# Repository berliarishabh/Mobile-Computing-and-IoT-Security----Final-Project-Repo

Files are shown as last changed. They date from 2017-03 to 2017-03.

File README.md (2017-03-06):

# Mobile-Computing-and-IoT-Security----Final-Project-Repo

#### Motivation:

With the advent of mass-deployed broadband Internet connections and the development of Wireless technologies (BLE, Zigbee etc.), smart connected devices in the home are a very real and practical possibility. 

A Smart Home is one that is designed to deliver or distribute a number of services within and outside the home through a range of networked devices. [Juniper Research]

#### Objective:

To develop a complete Internet of Thing system for a Smart Home such as Samsung SmartThings, Notion etc. This would require us to build individual BLE based Sensor Tags. Every Tag would have a specific sensor to sense parameters such as Temperature, Humidity, Ambient Light, Proximity, Pressure, Touch etc. 
These Tags will be built on the BLE Nano (based on the Nordic nRF51822 SoC). Each individual tag will have the sensor circuit interfaced with the BLE Nano and would run on a single coin-cell battery (CR-2032). We would use the Leopard Gecko EFM32 Board as one of the Tags as well to use the LESENSE sensor. 

The Sensor Tags would connect and transmit data to a small Microcomputer (Raspberry Pi 3) based hub. Since, the Raspberry Pi has Wi-Fi connectivity it enables us to take our data to the cloud, where the data processing would take place. 

We plan to use one of the following platforms to collect, visualize & analyze data and trigger responses accordingly:
•	Sci-kit Learn
•	ThingSpeak
•	Phant
This would allow us to host a web server on Rasp Pi for the User Interface where the User can monitor all the sensor data on Graphs and Issue Override Commands such as GetTemp, GetPressure etc.
If we are able to accomplish this well within our time bounds, we would try to implement an App to give notifications on the Phone.

Also, since we have the sensor data and trigger points we could use to actuate physical things inside your home e.g. Using the Ambient light and Temperature sensor data, a servo motor could be used to actuate your Window Blinds depending on the Light and temperature settings etc. 

There would be 2 set of Commands, Trigger Commands and Override Commands. 
Trigger Commands are sent through the ThingSpeak or Sci-Kit platform depending on the set points. If the sensor data goes above or below a notification would be given. These commands are even used to Actuate something if required.

Override Commands are sent by the user through the UI, these commands are to get the most recent Sensor Data and post it on the Screen.

#### Block Diagram of a System
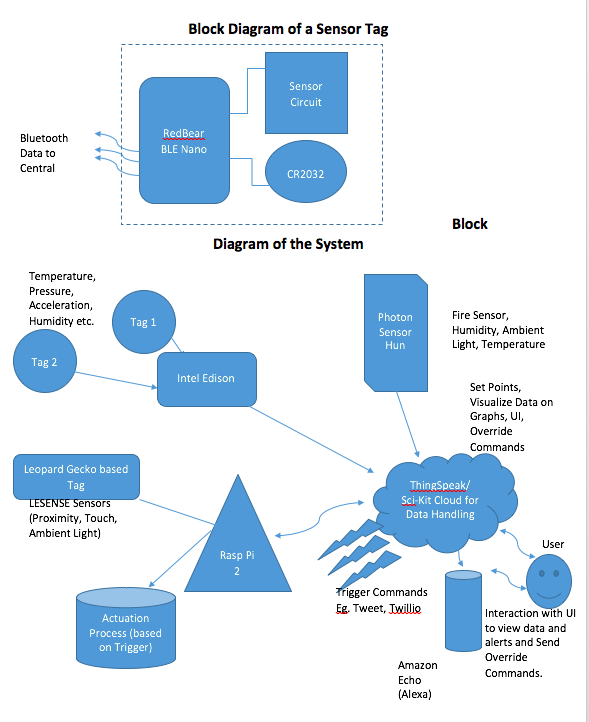
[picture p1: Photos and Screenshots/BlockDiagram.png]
block-diag


#### Block Diagram of the System
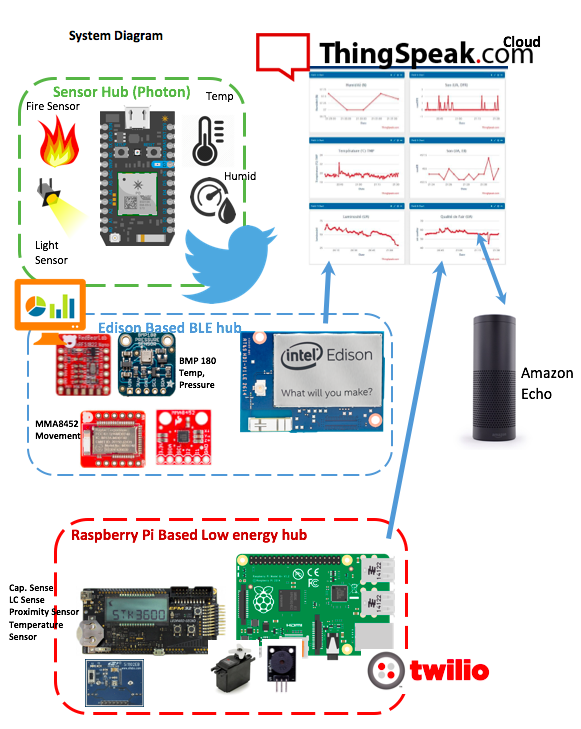
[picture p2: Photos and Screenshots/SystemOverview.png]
System-d


#### Test Methodology: 

1.	Testing functionality of individual Sensor Tags
  a.	Validate sensor data 
  b.	Testing if sensor tag posts data according to Set Points
  c.	Testing if sensor tag sends data when requested with a command.
2.	Testing the Server
  a.	Test individual sensor connections to the server
  b.	Test the Data Logging and setup Visualization through Graphs.
  c.	Testing the Trigger commands and Override Commands
3.	Integration and Testing
  Integration of the system and testing individual points

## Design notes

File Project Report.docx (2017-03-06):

Project Report

Handout

ECEN 5023:

Mobile Computing and IoT Security

Rishabh Berlia

Omkar Reddy Seelam

Proposed Objective¹:

c

1 As Submitted in Project Proposal

What was Implemented?

We were able to finish most of the Objectives we set.

There are 3 different modules in our Project. The first one Sensor Cubes.

We built 2 Sensor Cubes (instead of calling them tags). They are based on BLE Nano with an ARM M0 Processor. One Sensor Cube is for Temperature and Pressure (It has a BMP180 sensor on it). The other one is for Movement Detection (It has a MMA8452Q accelerometer.) Both the sensors communicate using I2C protocol.

They communicate with the Intel Edison Over Bluetooth protocol using the Bluez Python Library. The received data is then transmitted to the ThingSpeak channel.

The second one is a Sensor Hub based on Particle Photon Board. It is a Wi-Fi connectable board. It has a Thermistor, a Photocell Based Light Sensor, Fire Detection Sensor, Humidity Sensor. This peripheral boxes in one Housing and connects to the ThingSpeak cloud similarly via HTTP request. The Sensors in this hub are both Analog and Digital ones.

The third module or peripheral is the Leopard Gecko board, used in the class. This uses the Adafruit Bluefruit LE UART Friend connected to a Raspberry Pi via a Bluetooth 4.0. We built upon the Adafruit Python Library to send data from the Leopard Gecko to the Pi. We get the data as a 9bit string and parse the data accordingly. The data is then updated on ThingSpeak at the given interval.

We also implemented the Amazon Echo to act as the center of the Smart Home system. It helps you to read the sensor data and also send commands to the system.

System Diagram

Cloud

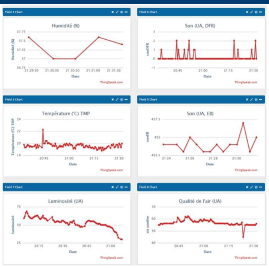
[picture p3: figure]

Sensor Hub (Photon)

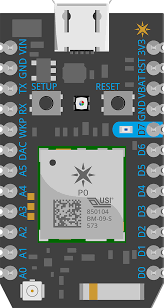
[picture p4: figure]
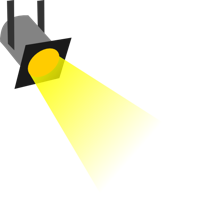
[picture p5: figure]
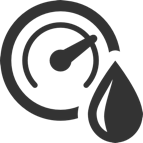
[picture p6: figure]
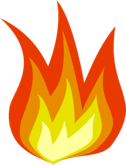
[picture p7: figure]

Fire Sensor

Temp Sensore

Humid Se

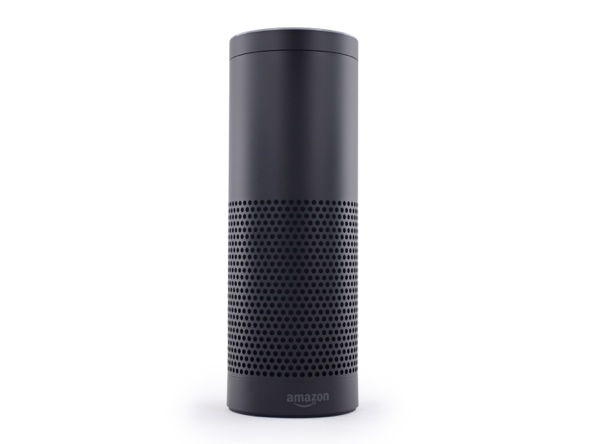
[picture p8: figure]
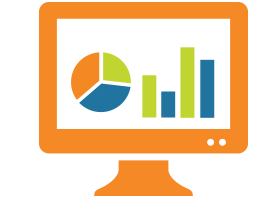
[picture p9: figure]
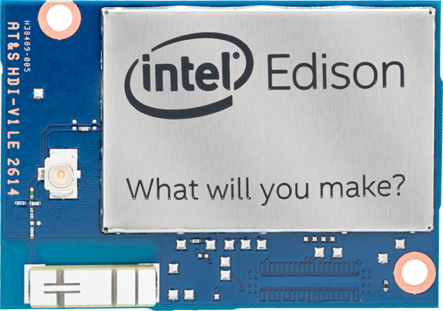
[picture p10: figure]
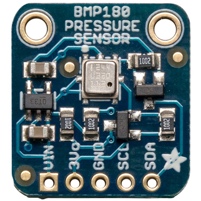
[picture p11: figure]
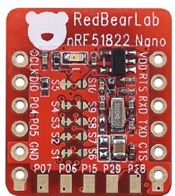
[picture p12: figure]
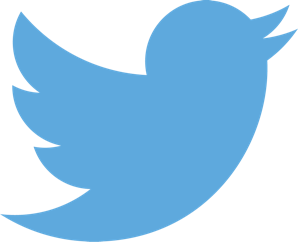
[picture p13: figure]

Light Sensor

MMA8452

Movement

BMP 180

Temp, Pressure

Amazon Echo

Edison Based BLE hub

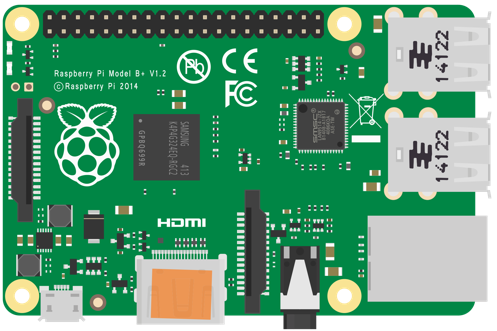
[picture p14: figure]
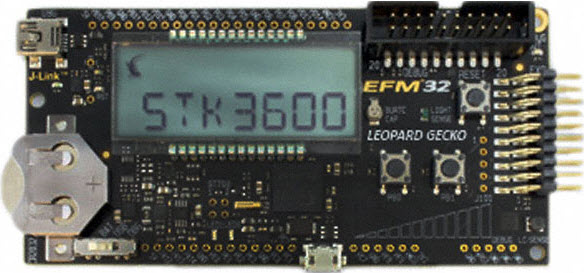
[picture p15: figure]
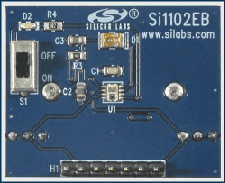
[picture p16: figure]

Raspberry Pi Based Low energy hub

Cap. Sense

LC Sense

Proximity Sensor

Temperature Sensor

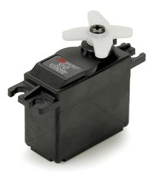
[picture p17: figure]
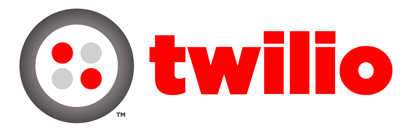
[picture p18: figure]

Block Diagram of a Sensor Tag

Sensor Circuit

RedBear

BLE Nano

Bluetooth Data to Central

CR2032

Block Diagram of the System

Photon Sensor Hun

Temperature, Pressure, Acceleration, Humidity etc.

Tag 1

Fire Sensor, Humidity, Ambient Light, Temperature

Tag 2

Intel Edison

Set Points, Visualize Data on Graphs, UI, Override Commands

Leopard Gecko based Tag

ThingSpeak/ Sci-Kit Cloud for Data Handling

Rasp Pi 2

LESENSE Sensors (Proximity, Touch, Ambient Light)

User

Trigger Commands

Eg. Tweet, Twillio

Actuation Process (based on Trigger)

Interaction with UI to view data and alerts and Send Override Commands.

Amazon Echo (Alexa)

Issues and What could not be completed.

We were aiming to also integrate the TI sensor tag in the system but we had some problems in reading data from it. Also we broke the side switch which is used to switch the system ON.

Also we are having problems with sending commands using Alexa. This is due to the University’s Private Network. We need a public IP to get the data from Alexa to actuate something.

We implemented the EEPROM Emulation but there are inconsistencies with our code.

We believe we could have made the system more consistent and given a better demo without making you and Shiva wait.

Summary

This was a very challenging project. We had a lot in mind and were able to implement most of it. We learnt a lot of new things.

We leant in depth about BLE services and learned to make a custom service. We still have to learn to write code to read from the custom library. This is the reason we have used existed profiles (Heart Rate) to receive data/send data.

We learnt different platforms to create a multiprotocol Wireless Sensor Network. Interfaced different IoT APIs with our project.

We learnt the Alexa API which is really fun to use. We created some models using sketch-up and learnt some 3D prototyping.

We learnt that anything that can go wrong will go wrong! You just have to be agile. Try to fix things with a new approach. We kept pretty much to the timeline apart from a few deviations.

We learnt Python in more depth. Also got to try a couple of new sensors.

Key Dates:

Duration (Week) | Task
~~03-13 to 03-19 (Week 1)~~ | ~~Acquiring Parts and Research~~
~~03-20 to 03-26 (Week 2)~~ | ~~Getting Sensor Tags ready (almost done)~~
~~03-27 to 04-02 (Week 3)~~ | ~~Finishing up with Sensor Tags~~
~~04-03 to 04-09 (Week 4)~~ | ~~Setting up the Sensor Network on Raspberry PI~~ ~~Complete Sensor Tags~~
~~04-10 to 04-16 (Week 5)~~ | ~~Setting up the Web Server using selected Platform~~ ~~EEPROM Emulation~~
04-17 to 04-23 (Week 6) | ~~Complete an Actuation System like the Automatic Window Blinds.~~ Integration with Amazon Echo
04-23 to 04-25 (Week 7) | Testing and Finishing up
04-26 (Week 7) | Project Demo

We kept to the schedule more or less which has happened the first time with us. It was due to the timely updates and status reports that were required which pushed us to complete our work on time.

Photos

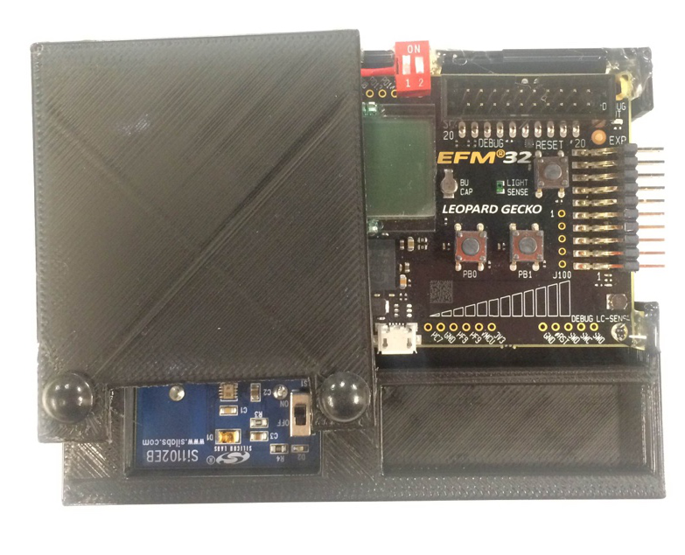
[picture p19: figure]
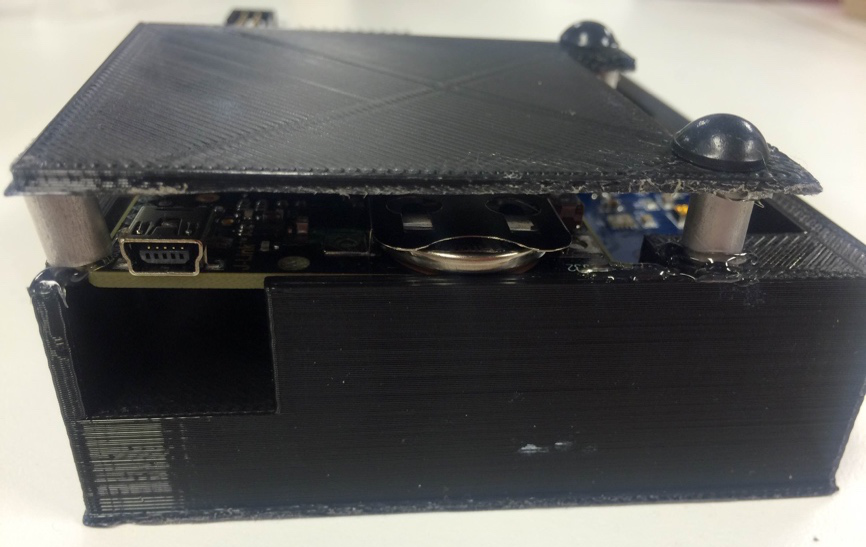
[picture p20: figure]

Figure 1 Leopard Gecko with housing (Top View)

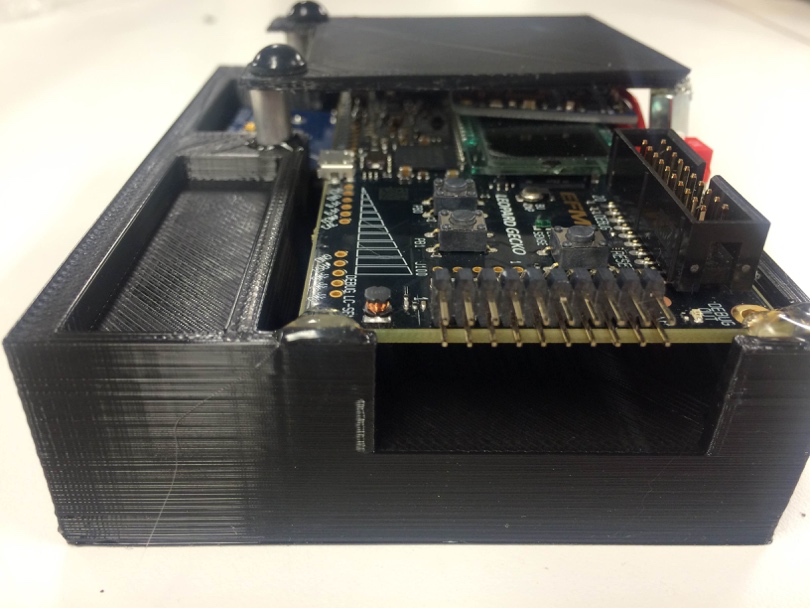
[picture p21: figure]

Figure 2 Leopard Gecko (Side View 1)

Figure 3 Leopard Gecko (Side View 2)

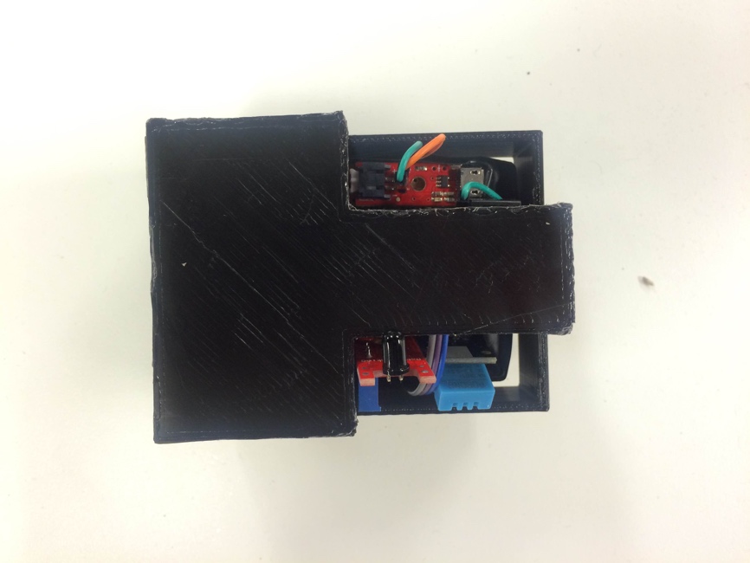
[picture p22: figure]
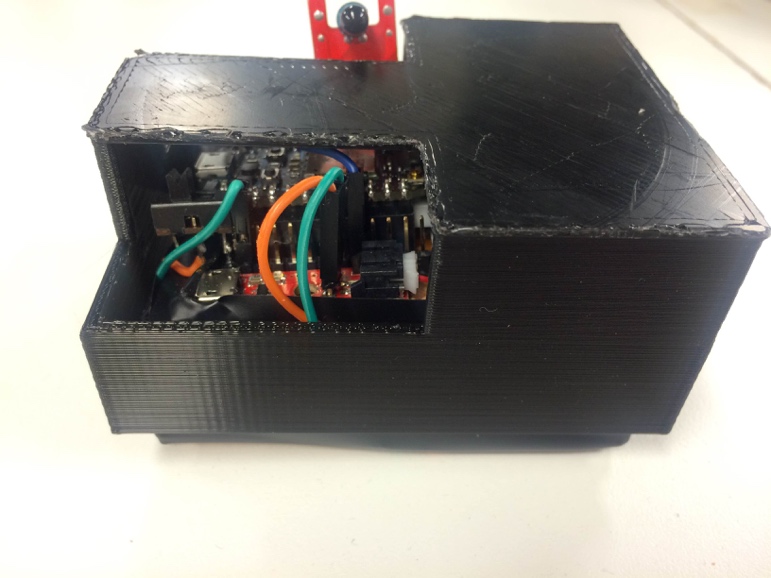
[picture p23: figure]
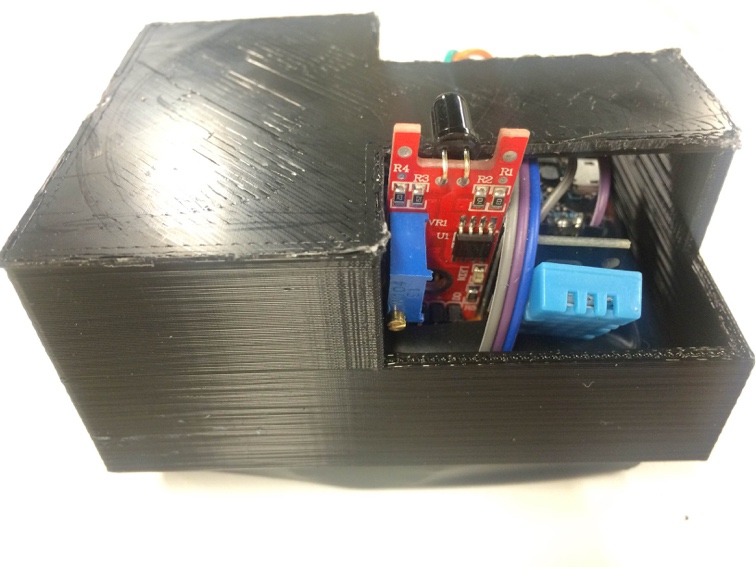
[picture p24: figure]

Figure 4 Photon Sensor Hub with Housing (Side View 1)

Figure 5 Photon Sensor Hub with Housing (Side View 2)

Figure 6 Photon Sensor Hub with Housing (Top View)

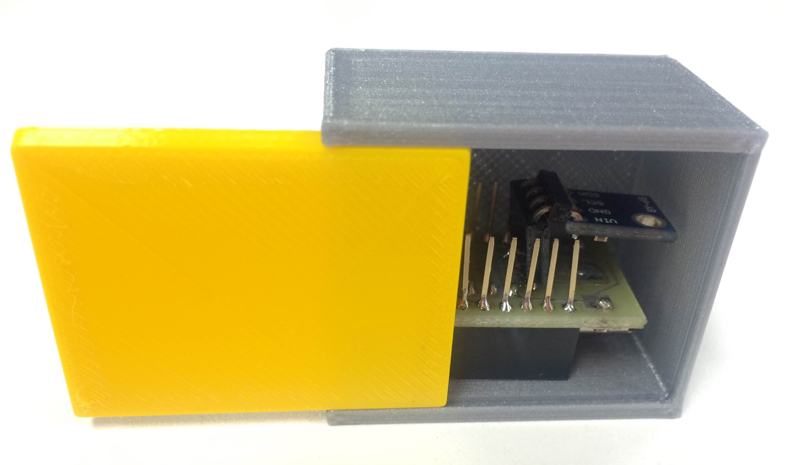
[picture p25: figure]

Figure 7 Accelerometer Cube (with Red Bear Nano)

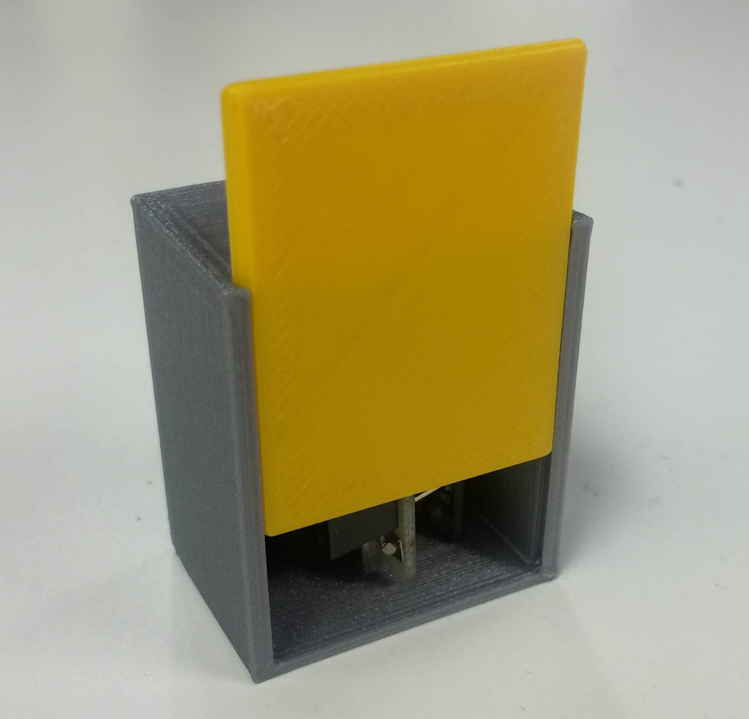
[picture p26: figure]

Figure 8 Temperature and Pressure Cube (with Red Bear Nano)

Acknowledgements

We would like to conclude by thanking a few people without whose help this project would have not been possible.

Firstly, we would like to Thank you Prof. Graham for scoping the project so well and giving us ample time for the project. We really liked the way the project was structured with the regular updates, it pushed us to complete it on time.

We would also Thank you for the forum and helping everyone through that medium, though we were not able to use that help much I believe it was really helpful for other students.

We would also extend our thanks to our TA, Shivashankar Gunashekhar for his help and suggestions during the project and otherwise. He has been a really hard-working TA and helped a lot of students like us during the entire semster. We would also Thank our friend Akshay Singh for helping us during the HackCU.

Lastly we would like to thank our friend from Aerospace Engineering for helping us in making the 3D parts using solid-works, without her help it wouldn’t have been easier to make the parts this quickly.

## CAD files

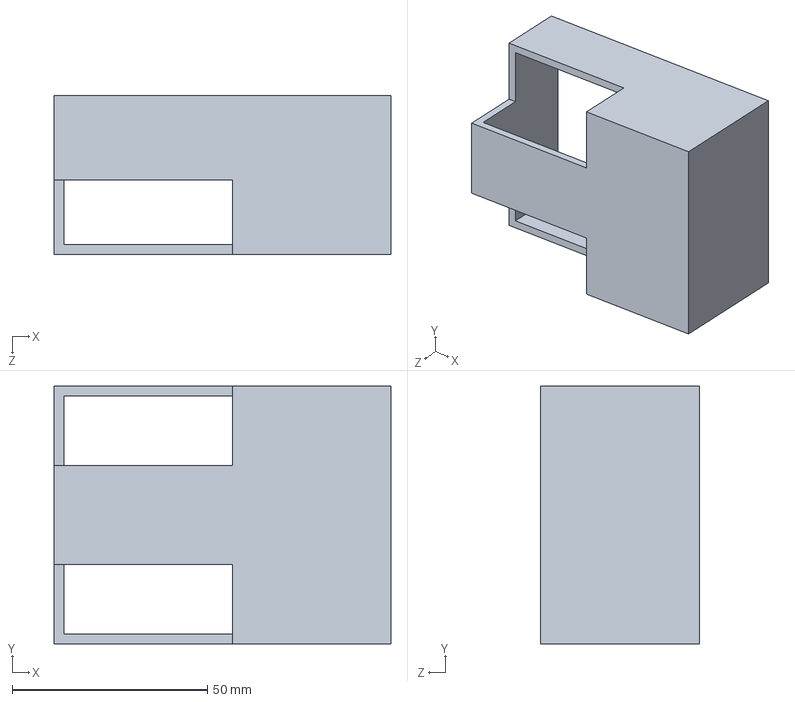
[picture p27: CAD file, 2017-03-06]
Schematics and Solidworks Parts/3D Printed Parts/PhotonBox.SLDPRT
86.4 x 66.0 x 40.6 mm

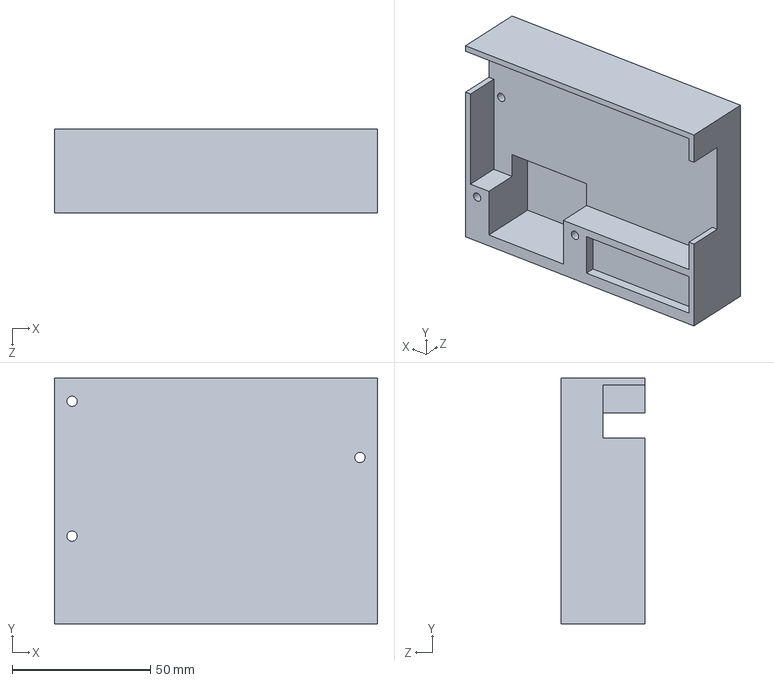
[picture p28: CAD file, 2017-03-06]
Schematics and Solidworks Parts/3D Printed Parts/Base_Gecko.SLDPRT
116.8 x 88.9 x 30.5 mm

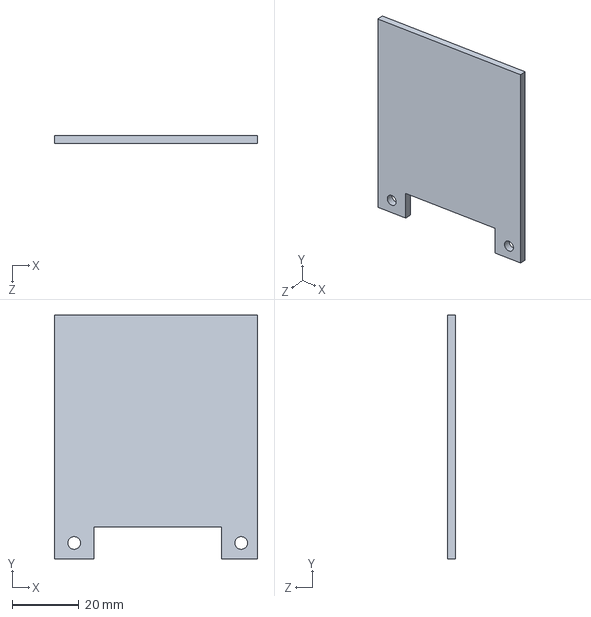
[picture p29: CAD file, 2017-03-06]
Schematics and Solidworks Parts/3D Printed Parts/TOP_Plate_Gecko.SLDPRT
61.0 x 73.1 x 2.54 mm

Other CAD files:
Schematics and Solidworks Parts/3D Printed Parts/Base_Gecko.STL
Schematics and Solidworks Parts/3D Printed Parts/PhotonBox.STL
Schematics and Solidworks Parts/3D Printed Parts/TOP_Plate_Gecko.STL

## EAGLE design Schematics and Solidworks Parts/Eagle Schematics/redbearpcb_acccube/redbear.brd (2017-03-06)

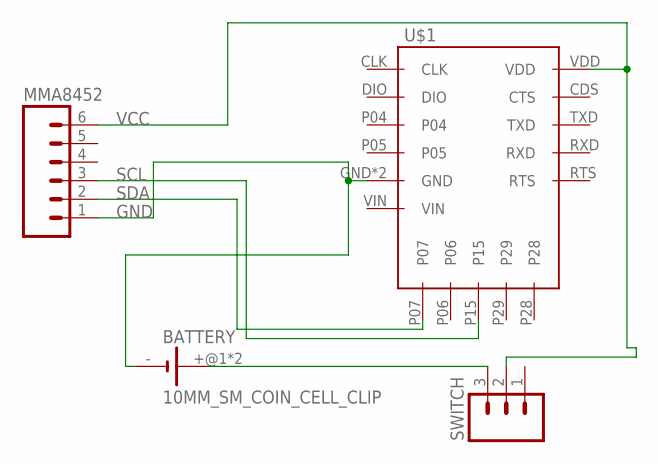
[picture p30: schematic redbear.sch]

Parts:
BATTERY: 10MM_SM_COIN_CELL_CLIP
MMA8452: M06NO_SILK_FEMALE_PTH; 1X06_NO_SILK
SWITCH: M03PTH; 1X03
U$1: REDBEAR_NANOBREAKOUT1; BREAKOUT

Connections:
GND: BATTERY.-, MMA8452.1, U$1.GND, U$1.GND1 (GND)
unnamed: BATTERY.+@1 (+), BATTERY.+@2 (+), SWITCH.3
SCL: MMA8452.3, U$1.P15
SDA: MMA8452.2, U$1.P07
VCC: MMA8452.6, SWITCH.2, U$1.VDD

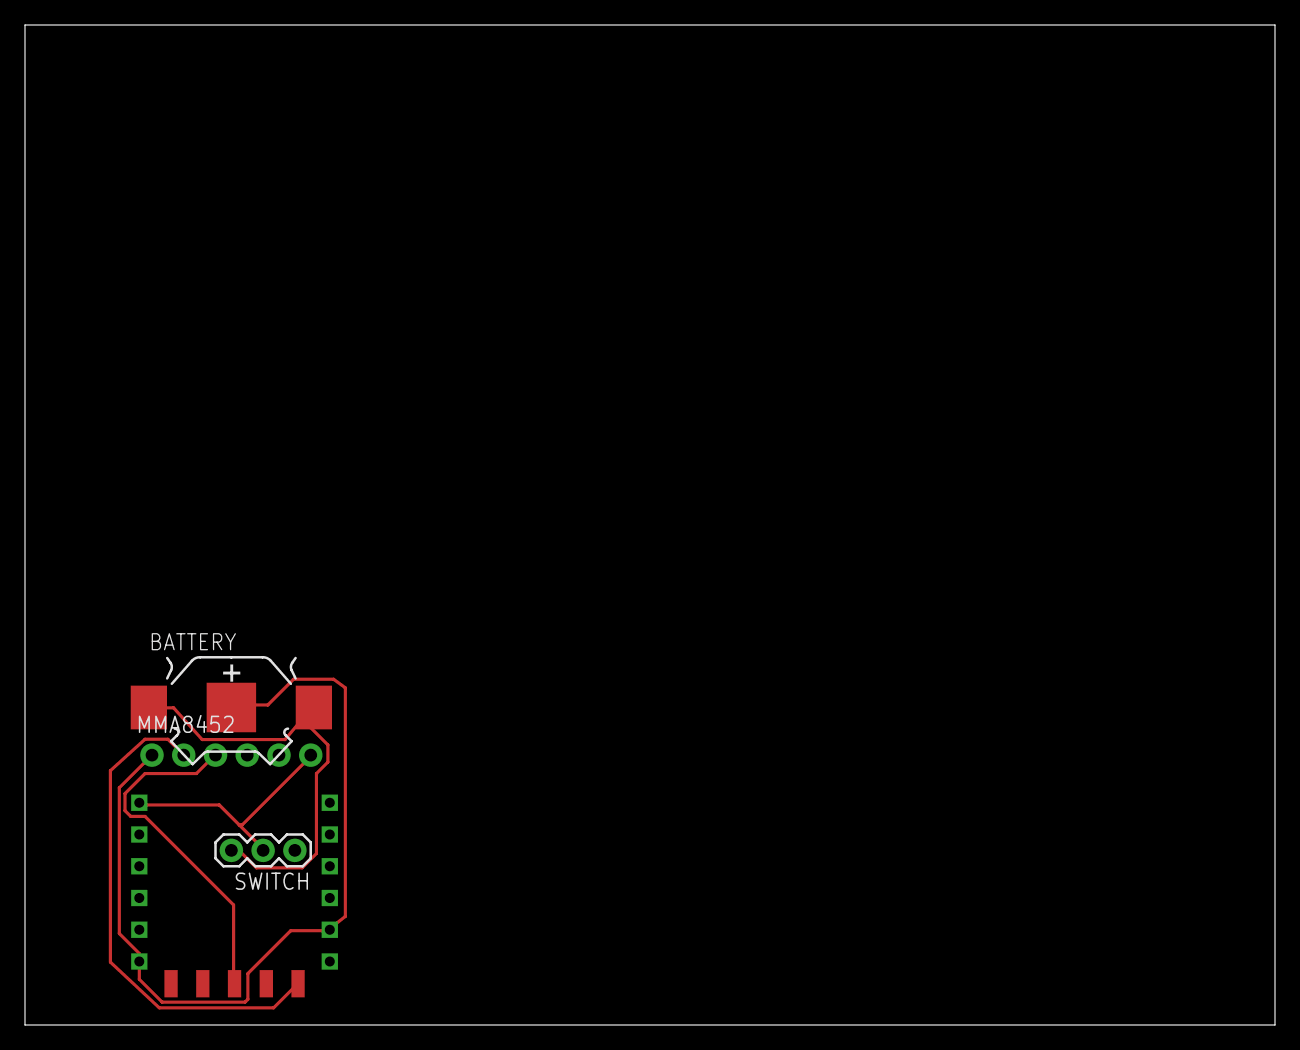
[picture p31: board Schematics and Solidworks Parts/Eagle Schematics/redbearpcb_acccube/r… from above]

Board: 2 copper layers, 100.0 x 80.0 mm, 4 parts (0 on the bottom side), 5 nets.

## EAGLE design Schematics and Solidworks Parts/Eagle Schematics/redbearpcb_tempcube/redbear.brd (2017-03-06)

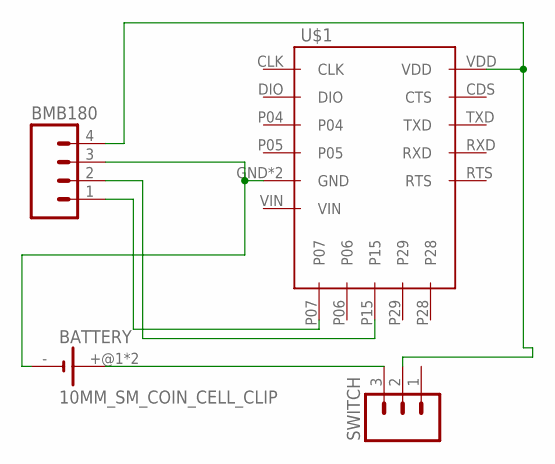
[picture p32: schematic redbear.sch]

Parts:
BATTERY: 10MM_SM_COIN_CELL_CLIP
BMB180: M04NO_SILK_ALL_ROUND; 1X04_NO_SILK_ALL_ROUND
SWITCH: M03PTH; 1X03
U$1: REDBEAR_NANOBREAKOUT1; BREAKOUT

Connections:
GND: BATTERY.-, BMB180.3, U$1.GND, U$1.GND1 (GND)
unnamed: BATTERY.+@1 (+), BATTERY.+@2 (+), SWITCH.3
SCL: BMB180.2, U$1.P15
SDA: BMB180.1, U$1.P07
VCC: BMB180.4, SWITCH.2, U$1.VDD

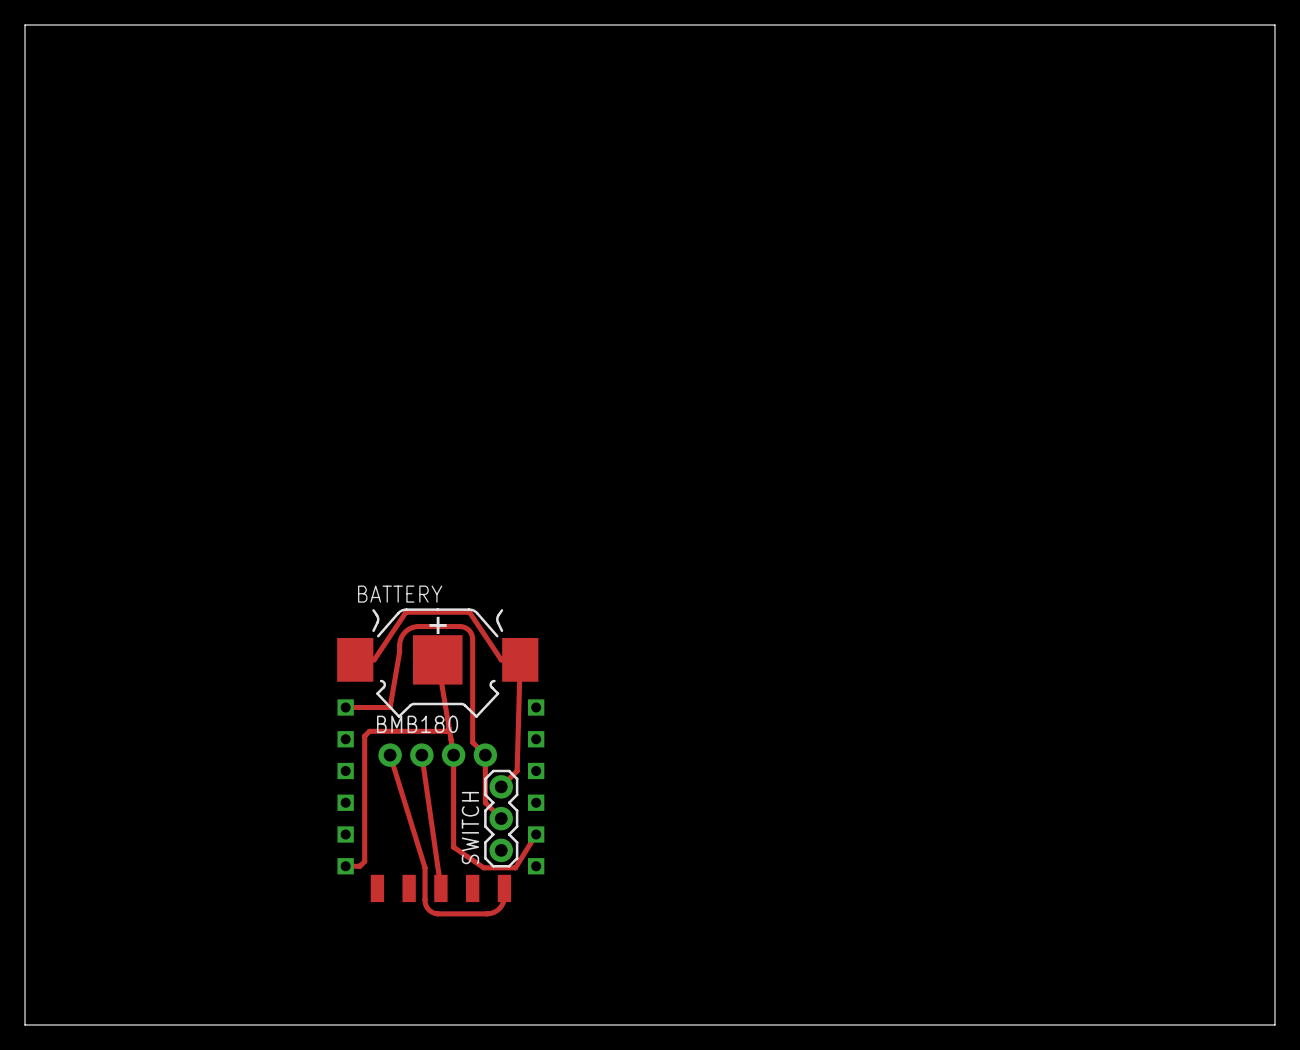
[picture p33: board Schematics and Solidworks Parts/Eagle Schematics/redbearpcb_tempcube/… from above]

Board: 2 copper layers, 100.0 x 80.0 mm, 4 parts (0 on the bottom side), 5 nets.

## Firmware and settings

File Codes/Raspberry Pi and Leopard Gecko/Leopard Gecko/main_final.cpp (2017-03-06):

/************************************************************************************************************
* Description :	Part of the Final Project for the Course Mobile Computing and IoT Security (ECEN5023)		*
* Author	  :	Omkar Reddy Seelam and Rishabh Berlia                                                       *
* Email		  : omkar.reddy15@gmail.com, omkar.seelam@colorado.edu, rishabh.berlia@colorado.edu				*
* Date		  : 4/28/2016																					*
************************************************************************************************************/

/* Features:
 * Sometimes the alerts are too frequent and redundant so, the alerts can be snoozed for certain time  : snoozeAlerts!
 * Fixed issues like multiple LESENSE sensors DMA_Tx overwrites (Used an if loop to check what sensors have been triggered)
 * Negative temperatures issue has been fixed
 *
 * Different modes:
 * ***** Verbose mode : Where it sends lengthy messages such as "The temp is ....."
 * ***** switchToRPi : Where it waits for the command from the RPi whenever requested and responds accordingly
 * ***** !switchToRPi (default mode) : In which the LG sends a custom 9 Byte data packet every 4 seconds. The data packet has following info:
 * 										Y/N : {IntrusionState, DoorState, LightState, SecurityState, Temperature : +/- XX.X}
 * 										The main idea was that the sensors modify the data packet whenever a change in state is observed using interrupts
 * 										and the current data packet at each 4 seconds interval is sent through bluetooth.
 * 						You can switch between switchToRPi modes using the PusbButton0
 * Monitored using:
 * ***** The program has been structured in a way that it provides flexibility to use the LG with a RPi or
 * 		 any BLE application on a SmartPhone or computer.
 * 		 This can be done using the pushbutton0.
 *		 Care has been taken such that the sensor data stream sent makes sense not only for a RPi but also on the applications.
 *		 For this reason the custom packet of 9 bytes mentioned above has been chosen.
 * */

/* Project Requirements:
 * EEPROM Emulation has been implemented to restore the SecurityState during a reset, but it was not consistent. Did not get enough time to fix the issue.
 * */

/* LC SENSE + LIGHT SENSE + TEMPERATURE SENSE
 * 1. LESENSE AND TEMP SENSE LEUART DMA_TX dont overwrite. If there is a LEUART DMA_Tx in progress, it simply skips any new LEUART DMA_Tx requests
 * 2. In this version IF LIGHT SENSE DMA_Tx requests (if LC AND LIGHT are both on), because LC SENSE is being serviced first in the LESENSE IRQ.
 * 		A way has to be implemented to not skip any of the particular LESENSE DMA_Tx reqyests by using multiple combinations of
 * 3. LCSENSE Snooze has been made global to all the LESENSE sensors; All alerts will be snoozed
 * */

/* LC Sensor + ADC Temperature Sensor (from Assignment 5)
	1. multiple DMA writes dont interrupt the previous write;
	2. Simply skips the new write if an existing DMA LEUART Tx is happening; Used DMA_IDLE flag
*/

/* LC SENSOR FINAL:
 * 1. Turns on LED0 when the window is open (when there is no metal)
 * 	  There is LETIMER0 interrupting every 4 seconds; If the LED0 is on, then it is turned off; If there is no metal
 * 	  	detected in the next scan cycle; The Led0 is immediately turned on again.
 * 	  	So, a On/Off of LED0 can be observed when there is no metal nearby.
 * 2. Notifications sent through BLE when there is no metal nearby i.e, when window is open. Notified every scan cycle
 * 3. Notifications can be snoozed for about LCSENSE_SNOOZECOUNT times the LETIMER0 interrupts => (SnoozeCount * LETIMER0 interrupts)
 * 		After the snooze time, the notifications resume if the window is still open;
 * 		Meanwhile the LED0 performs the same behaviour of On/Off during the entire snooze cycle or untill a metal comes nearby i.e, until the window is closed
 * . The Threshold for LC Sensor is hardcoded; Should implement a way in which the input is taken from the user
 * */

// Include Libraries
#include "mbed.h"       // mbed libraries; includes sleep()
#include "em_device.h"
#include "em_chip.h"    // for chip related libraries
#include "sleepmodes.h" // to use blockSleepMode() and unblockSleepMode()
#include "em_letimer.h"	// for LETIMER functions; LETIMER_CompareSet, etc
#include "em_gpio.h"	// For GPIO setup
#include "em_adc.h"		// For ADC
#include "em_dma.h"		// For the DMA
#include "em_leuart.h"	// For the LEUART
#include "string.h"		// For string manipulation functions; string copy, string concatenation
#include "em_lesense.h"	// For LESENSE setup
#include "em_acmp.h"	// ACMP used for sensor measurements (LESENSE)
#include "em_dac.h"		// DAC used for excitation and reference (LESENSE)
#include "em_int.h"		// For Enabling/Disable Interrupts Globally
#include "em_i2c.h"
#include "i2c_api.h"
#include "eeprom_emulation.h"

/* MACROS DECLARATION */
#define BLE_COMPLETELY_OFF					true

// BLE Connection to either SmartHome System (final project) or on the APP (for debug)
#define BLE_VERBOSE							false
#define LIGHTSENSE_TIMER_RESET				true
#define LCSENSE_TIMER_RESET					true
#define LIGHTSENSE_TIMEOUT					false
#define LCSENSE_TIMEOUT						false
#define SWITCHTORPI_BUTTON_PORT				gpioPortB
#define SWITCHTORPI_BUTTON_PIN				9U
#define SWITCHTORPI_BUTTON					SW0					// or PB9
uint32_t smartHome_temperature = 0;								// Temperature part of the packet
uint32_t smartHome_security = 0;								// Sends the security fields
char smartHomeMessage[] = "NNNN+00.0\r\n";						// Y/N : {Proximity, LC, LIGHT, SECURITY, +/- XX.X}
char command_smartHomeMessage[] = "leopardPacket!";
bool switchToRPi = false;										// Doesnt send message every 4 seconds. Sends data only when requested. Can be done by using a timer on RPi
char switchingToRPi[] = "Switching to RPi\r\n";
char switchingBackFromRPi[] = "Switching back from RPi\r\n";
bool LIGHTSENSE_TIMER = LIGHTSENSE_TIMER_RESET;					// defaulted to true
bool LCSENSE_TIMER = LCSENSE_TIMER_RESET;							// defaulted to true
InterruptIn	switchTORPi_button(SW0);

// Common Variables
#define DEBUG_MODE 					0						// Make this value to 0; To enable Serial print and BCP trace (code-correlation)
#define LOWPOWER_USING_SLEEPONEXIT 	0						// Using SLEEPONEXIT; Even Lower Energy program can be achieved
#define INV_LEUART_DATABITS			0						// Invert LEUART Data bits; While not transmitting

// LETIMER Variables
#define ULFRCO_Freq 				1000					// Frequency of ULFRCO is 1KHz
#define SAMPLEPERIOD 				4						// Total Required period in Seconds

// DMA Setup Variables
#define DMA_CHANNEL_ADC 			2						// DMA channel select - ADC0
#define DMA_CHANNEL_LEUART_RX 		0						// DMA channel select - LEUART RX
#define DMA_CHANNEL_LEUART_TX 		1						// DMA channel select - LEUART TX
#define DMA_ADC_PRIORITY 			false					// DMA Channel Priority for ADC
#define DMA_LEUART_TX_PRIORITY 		false					// DMA Channel Priority for	LEUART TX
#define DMA_LEUART_RX_PRIORITY 		false					// DMA Channel Priority for LEUART RX
#define DMA_ADC_ARBITRATE 			dmaArbitrate1			// ADC Arbitrate rate
#define DMA_LEUARTRX_ARBITRATE 		dmaArbitrate1			// LEUART RX Arbitrate rate
#define DMA_LEUARTTX_ARBITRATE 		dmaArbitrate1			// LEUART TX Arbitrate rate
#define LEUART0_BUFF_MAX 			1023					// Buffer size for LEUART0
#define DMA_LEUARTRX_TRANSFERS 		LEUART0_BUFF_MAX 		// DMA Transfers to be done on LEUART0->RXDATA

// ADC Setup Variables
#define ADC_SAMPLESREQUIRED 		200						// The required number of samples
#define ADC_REFERENCE 				adcRef1V25				// Single Conversion Reference for Temperature sensor
#define ADC_INPUTCHANNEL 			adcSingleInpTemp		// Selecting the input channel; Temperature sensor
#define ADC_RESOLUTION 				adcRes12Bit				// Selecting the resolution
#define ADC_ACQTIMECYCLES 			adcAcqTime2				// Calculated Acquisition time
#define ADC_CLOCKFREQ 				857000					// Required ADC Clock Frequency

// LEUART Setup Variables
#define LEUART0_LOOP_BACK			false
#define LEUART0_BAUDRATE 			9600					// LEUART0 BaudRate
#define LEUART0_DATABITS 			leuartDatabits8			// Number of data bits for LEUART0
#define LEUART0_PARITY 				leuartNoParity			// Parity bit enable/disable
#define LEUART0_STOPBITS 			leuartStopbits1			// Number of Stop bits
#define LEUART0_SIGFRAME			'!'						// The SIG Frame for LEUART0

// Temperature Settings

#define TEMP_UPPERLIMIT_DEFAULT 			30						// Temperature Sensor Upper Limit = 30degreesC [LED1]
#define TEMP_LOWERLIMIT_DEFAULT 			15						// Temperature Sensor Upper Limit = 15degreesC [LED0]

#define TEMPERATURE_SIZE					8						// Size of the Temperature reading appended to the transmitted message
#define CHECK_NEGATIVE_TEMPERATURES			false					// Flag to check if negative temp are being printer; subtracts 25 degrees

// GPIO variables
#define LED_PORT 					gpioPortE				// LED pin port
#define LED0_PIN 					2U						// LED0 Pin
#define LED1_PIN 					3U						// LED1 Pin
#define LED_PORT_DRIVEMODE 			gpioDriveModeLowest		// Drive strength for LED0
#define LED_PORT_CONFIG 			gpioModePushPullDrive	// Drive strength for LED1
#define BLUEFRUIT_CTS_PORT			gpioPortD				// Bluefruit CTS Pin connected to PortD of Leopard Gecko
#define BLUEFRUIT_CTS_PIN			15U						// Bluefruit CTS is connected to PortD Pin 15
#define BLE_SWITCH					false
#define BLE_SWITCH_PORT				gpioPortD
#define BLE_SWITCH_PIN				10U
#define PROXIMITY_SENSOR_PORT		gpioPortA
#define PROXIMITY_PIN_VDD			PA14
#define PROXIMITY_PIN_SIG			PA12

// Bluefruit AT Command Variables
#define BLE_CONFIGURATION			false								// Perform BLE Configuration
#define FACTORYRESET				"AT+FACTORYRESET\n"					// Perform Factory Reset before configuring the BLE
#define SWITCHMODE					"+++\n"
#define TX_POWERLEVEL				"AT+BLEPOWERLEVEL=0\n"				// BLE Radio TX power level (dBm); -40,-20,-16,-12,-8,-4,0,4
#define GAP_INTERVAL				"AT+GAPINTERVALS=50,4000,250,50\n"	// (Min ConnInt,Max ConnInt, AdvInt, AdvTimeout)
#define CONNECTION_STATUS			"AT+GAPGETCONN\n"					// Get the connection status
#define HW_MODE_LED					"AT+HWMODELED=disable\n"			// Manipulate HW Mode led; disable(0), mode(1), hwuart(2), bleuart(3), spi(4), manual(5,on/off/toggle)
#define ECHO						"ATE=0\n"							// Enable/Disable Echo
#define SYS_RESET					"ATZ\n"								// System Reset
#define BLE_TIMEOUT					5									// Number of Retries for each command

// LESENSE
#define LESENSE_ACMP_CHANNEL		acmpChannel6	// Doesnt Matter; Any channel can be given because it is controlled by the LESENSE
#define ALERTS_SNOOZECOUNT				10			// LCSENSE Alerts Snooze time is around SnoozeCount*LETIMER_SAMPLEPERIOD
#define LESENSE_CHANNELMASK_6			0x40		// Channal mask for Channel 6 (0x1UL << 6)
#define LESENSE_CHANNELMASK_7			0x80		// Channel mask for Channel 7 (0x1UL << 7)
#define LESENSE_CHANNELMASK_8			0x100		// Channel mask for Channel 8 (0x1UL << 8)
#define LESENSE_CHANNELMASK_11			0x800		// Channel mask for Channel 11(0x1UL << 11)

// LC Sensor Macros
#define LCSENSE_PORT		   		gpioPortC		// LCSENSE Excitation and Measurement Port
#define LCSENSE_PIN			   		7U				// LCSENSE Excitation Measurement Pin
#define LCSENSE_DAC_DATA	   		800				// DAC input for LC Sensor
#define LCSENSE_DAC_CHANNEL	   		1				// DAC Channel for LC Sensor
#define LCSENSE_ACMP_CHANNEL		acmpChannel7	// ACMP Channel for LC Sensor
#define LCSENSE_LESENSE_CHANNEL		7				// LESENSE channel 7 for LC Sensor
#define LCSENSE_LIGHTSENSE_CHANNEL	6				// LESENSE channel 6 for Light Sensor
#define LCSENSE_SCAN_FREQ_Calb		20				// LC Sense Scan Frequency in Hz for Calibration
#define LCSENSE_SCAN_FREQ			1				// LC Sense Scan Frequency in Hz after Calibration
#define ACMP_NEG_REF           		acmpChannelVDD	// Use VDD as ACMP Negative reference
#define ACMP_VDD_SCALE         		0x0D            // Reference for the LC sensor to be close to the DAC voltage This was calibrated using a scope and probing both the LC sensor and the ACMP output
												// From the Software Example
// Calibration Settings
#define LESENSE_MAX_CHANNELS 			16				// LESENSE Channels
#define BUFFER_INDEX_LAST  				15				// Last Buffer Index
#define LCSENSE_MANUAL_THRESHOLD		0x0B			// LCSENSE threshold
#define LCSENSE_THRESHOLD_HYSTERESIS	0x03			// Hysteresis for LC Sense threshold

// LIGHTSENSE Macros
#define LIGHTSENSE_EXCITE_PORT   	gpioPortD
#define LIGHTSENSE_EXCITE_PIN    	6U
#define LIGHTSENSE_SENSOR_PORT   	gpioPortC
#define LIGHTSENSE_SENSOR_PIN    	6U
#define LIGHTSENSE_ACMP_THRESHOLD 	33				// Lesser value means more light needed to turn the LED ON; LED ON => LIGHTS ON
#define LIGHTSENSE_LESENSE_CHANNEL		6

// Capsense
#define CAPSENSE_LESENSE_CHANNEL	8
#define CAPSENSE_PORT				gpioPortC
#define CAPSENSE_PIN				8U

// Proximity Sensor Macros
#define PROXIMITY_PORT				gpioPortA
#define PROXIMITY_PIN				14U
InterruptIn proximitySensorSIG(PROXIMITY_PIN_SIG);

// EEPROM Macros
#define EEPROM_EMULATION			true

/** Default configuration for alternate excitation channel. */
#define LESENSE_LIGHTSENSE_ALTEX_CH_CONF                                       \
{                                                                              \
  true,                   /* Alternate excitation enabled.*/                  \
  lesenseAltExPinIdleDis, /* Alternate excitation pin is low in idle. */ \
  true                    /* Excite only for corresponding channel. */        \
}

/** Default configuration for alternate excitation channel. */
#define LESENSE_LIGHTSENSE_ALTEX_DIS_CH_CONF                                   \
{                                                                              \
  false,                   /* Alternate excitation enabled.*/                  \
  lesenseAltExPinIdleDis,  /* Alternate excitation pin is disabled in idle. */ \
  false                    /* Excite only for corresponding channel. */        \
}

/** Default configuration for all alternate excitation channels. */
#define LESENSE_LIGHTSENSE_ALTEX_CONF                                          \
{                                                                              \
  lesenseAltExMapALTEX,                                                         \
  {                                                                            \
    LESENSE_LIGHTSENSE_ALTEX_CH_CONF,     /* Alternate excitation channel 0. */\
    LESENSE_LIGHTSENSE_ALTEX_DIS_CH_CONF, /* Alternate excitation channel 1. */\
    LESENSE_LIGHTSENSE_ALTEX_DIS_CH_CONF, /* Alternate excitation channel 2. */\
    LESENSE_LIGHTSENSE_ALTEX_DIS_CH_CONF, /* Alternate excitation channel 3. */\
    LESENSE_LIGHTSENSE_ALTEX_DIS_CH_CONF, /* Alternate excitation channel 4. */\
    LESENSE_LIGHTSENSE_ALTEX_DIS_CH_CONF, /* Alternate excitation channel 5. */\
    LESENSE_LIGHTSENSE_ALTEX_DIS_CH_CONF, /* Alternate excitation channel 6. */\
    LESENSE_LIGHTSENSE_ALTEX_DIS_CH_CONF  /* Alternate excitation channel 7. */\
  }                                                                            \
}

/* GLOBAL VARIABLES */
// Common Variables
bool DMA_ADC_transferComplete 	= true;				// Flag to check DMA transfer status of ADC samples
bool DMA_IDLE					= true;
// Enable the Security; Turn the LC Sensor, Light Sensor, Proximity Sensor and Gesture Sensor On
bool SECURITY_ON = false;
DMA_CB_TypeDef cb[DMA_CHAN_COUNT];					// Type Definition for the DMA Call back functions
volatile uint16_t ADC_Buffer[ADC_SAMPLESREQUIRED];	// RAM Buffer for ADC DMA transfer
char Rx_Buffer[LEUART0_BUFF_MAX];		// Receive Buffer for LEUART DMA transfers
float temperature = 0;								// Variable for temperature
uint16_t TEMP_LOWERLIMIT = 0x24;
uint16_t TEMP_UPPERLIMIT = 0x25;
//#if DEBUG_MODE
Serial pc(USBTX, USBRX);    						// To enable pc.printf() statements; un-comment this and use pc.printf("Text\n\r") for printing text on the terminal
//#endif

// LETIMER Variables
uint16_t LETIMER_TOP;								// LETIMER Reset value-COMP0

// LESENSE Global Variables
// LC SENSE
bool CHECK_LCSENSOR_COUNT 		= false;		// To check the count when a metal object is placed/removed
bool MANUAL_THRESHOLD 			= true;
bool NOTIFY_ALERTS 				= true;

// Temperature Sensor Alerts
uint32_t leuartif;													// variable for saving LEUART interrupt flags
char below[] 			= "Temperature BELOW set min : ";			// Lower limit transfer string
char below_negative[] 	= "Temperature BELOW set min: -";			// Lower limit transfer string
char above[] 			= "Temperature ABOVE set max : ";			// Upper limit transfer string
char return_temp[] 		= "\r\nTemperature is : ";					// Return Temperature request string
char return_temp_neg[] 	= "\r\nTemperature is: -";					// Return Temperature request string
char cmdError[] 		= "\r\nERROR: Invalid command\r\n";			// Error message string
char command_RetTemp[] 	= "RetTemp!";								// The command for requesting temperature

// Alerts
char command_alertsSnooze[] 	  = "snoozeAlerts!";							// Command to snooze alerts
char alertsSnoozed[]			  = "\r\nSnoozed alerts for 40s\r\n";				// Response that the alerts have been snoozed
char windowOpenLightOn[]		  = "Window Open, Light On\r\n";				// Alerts
char windowOpenLightOnIntrusion[] = "Window Open, Light On and Intrusion\r\n";
char windowOpenIntrusion[]		  = "Window Open, Intrusion\r\n";
char lightOnIntrusion[] 		  = "Light On, Intrusion\r\n";


// LC Sensor Alerts
char windowOpen[] 		= "Window is open\r\n";					// Alerts
char windowClose[] 		= "Window is closed\r\n";
uint8_t snoozeTime 		= ALERTS_SNOOZECOUNT;					// The default snooze count. It is 10 LETIMER0 interrupt cycles

// Light Sensor Alerts
char lightOn[]			= "Light is On\r\n";					// Alerts

// Cap Sensor Alerts
char command_securityOn[]	= "securityOn!";					// Command to turn on security
char command_securityOff[]	= "securityOff!";
char securityOn[]			= "\r\nSecurity turned On\r\n";
char securityOff[]			= "\r\nSecurity turned Off\r\n";

// Proximity
bool INTRUSION_DETECTED = false;
char intrusion[] = "Intrusion Detected\r\n";

// BLE Configuration Variables
char check_1OK[] 	= "1\r\nOK\r\n";				// Different responses from the Bluefruit when in AT mode
char check_0OK[] = "0\r\nOK\r\n";
char check_OK[] = "OK\r\n";
char check_ERROR[] = "ERROR\r\n";

/********************************************************EEPROM EMULATION RELATED SECTION*******************************************************/

/***************************************** RAM_INTERRUPT.C ********************************************************/
/* Find the correct size of the interrupt vector */
#if defined(_EFM32_GECKO_FAMILY)
#define VECTOR_SIZE (16+30)
#elif defined(_EFM32_TINY_FAMILY)
#define VECTOR_SIZE (16+23)
#elif defined(_EFM32_GIANT_FAMILY)
#define VECTOR_SIZE (16+38)
#else
#error "Unknown Vector size"
#endif

/* Align the RAM vector table */
#if defined (__ICCARM__)
#pragma data_alignment=256
uint32_t vectorTable[VECTOR_SIZE];
#elif defined (__CC_ARM)
uint32_t vectorTable[VECTOR_SIZE] __attribute__ ((aligned(256)));
#elif defined (__GNUC__)
uint32_t vectorTable[VECTOR_SIZE] __attribute__ ((aligned(256)));
#else
#error "Undefined toolkit, need to define alignment"
#endif

/* SysTick interrupt handler. Counts ms ticks */
volatile uint32_t msTicks = 0;

/* Place interrupt handler in RAM */
#if defined (__ICCARM__)               			/* IAR compiler */
__ramfunc
#elif defined(__CC_ARM)
 __attribute__ ((section ("ram_code")))
#elif defined(__GNUC__)                  		/* GCC based compilers */
#if defined (__CROSSWORKS_ARM)         			/* Rowley Crossworks */
__attribute__ ((section(".fast")))
#else                           						/* Other GCC */
__attribute__ ((section(".ram")))
#endif
#endif

void SysTick_Handler(void){
  msTicks++;
}

void moveInterruptVectorToRam(void){
  memcpy(vectorTable, (uint32_t*)SCB->VTOR, sizeof(uint32_t) * VECTOR_SIZE);
  SCB->VTOR = (uint32_t)vectorTable;
}

/*****************EEPROM VARIABLES**********************************/
#define EEPROM_PAGES_NUMBER 2

/* Define the non-volatile variables. */
EE_Variable_TypeDef ee_security_on;

uint16_t             readValue;

/***************************************************************************************************************************************/
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
int main(void){
	CHIP_Init();
	/*EEPROM_Initialization();
	EEPROM_ReadSettings();*/
	blockSleepMode(EM2);
	pc.printf("Welcome");
	INT_Disable();

	#if DEBUG_MODE
	BSP_TraceSwoSetup();    		// power analysis for specific code section
	#endif

	// Peripheral Initialization
	CMU_setup();			// Setup all oscillators and clocks required
	GPIO_setup();			// Setup the LEDs, LESENSE excitation/measurement pins
	DAC_setup();			// Setup required DAC output for LC Sense excitation
	ACMP_setup();			// ACMP setup for LC Sense comparision
	ACMP1_setup();
	LETIMER_setup();		// Letimer for turning the LED off in 2 seconds every time the LC sensor is triggered
	ADC_setup();			// ADC Setup for Temperature Sensor
	LESENSE_setup();		// LESENSE initialization

	// Peripheral initialization for Communication using Bluefruit
	DMA_setup();					// Base DMA setup
	DMA_ADC_Setup();				// DMA Setup for ADC
    DMA_LEUART_TX_Setup();			// DMA setup for LEUART Tx
    DMA_LEUART_RX_Setup();			// DMA setup for LEUART Rx
	LEUART_setup();					// LEUART setup

	PROXIMITY_initSetup();			// Setup the Proximity Sensor
	switchTORPi_setup();			// switch to sending data every 4 seconds to waiting for command to send the packet; Using Pushbutton0

	#if BLE_SWITCH
	GPIO_PinModeSet(BLE_SWITCH_PORT, BLE_SWITCH_PIN, gpioModePushPull, 1);	// BLE Switch
	#endif

	#if BLE_CONFIGURATION
	BluetoothManipulation();
	#endif

	INT_Enable();

	// EEPROM emulation failed; So, the default values max and min values are set to be 30 and 15 respectively
	TEMP_UPPERLIMIT = 30;
	TEMP_LOWERLIMIT = 15;

	while(1){
		sleep();	// Sleep tight
	}
}

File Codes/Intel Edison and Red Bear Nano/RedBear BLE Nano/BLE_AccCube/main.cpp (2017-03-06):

/* Source Code for Hear Rate Monitor obtainfrom the mbed Microcontroller Library
 * Copyright (c) 2006-2015 ARM Limited. Licensed under the Apache License, Version 2.0 (the "License");
 * This is the modified version of the said code. 
 *
 * Modified code written by: Omkar Reddy and Rishabh Berlia
 * 
 * Description: This code uses the BLE_HeartRateMonitor example from mbed to transmit Temperature and Pressure values obtained from the BMP180
 * The MMA8452 communicates to the BLE Nano via I2C. We have used the MMA8452 library written by Ashley Mills, Nicholas Herriot (See MMA8452.cpp) and edited it according to our application.
 * 
 */


#include "mbed.h"
#include "MMA8452.h"
#include "ble/BLE.h"
#include "ble/services/HeartRateService.h"
#include "ble/services/HealthThermometerService.h"
#include "ble/services/DeviceInformationService.h"


MMA8452 acc(P0_7, P0_15, 100000); //Declare the SCL(P0_15) and SDA(P0_7) ports and make an instance called i2c. Also pass the sample frequency for the accelerometer in Hz.
Serial pc(USBTX,USBRX);

int x, y, z;       //Variables to get the X axis, Y axis and Z axis
int Px,Py,Pz = 0;  //Previous accelerometer values
int Cx,Cy,Cz;      //Current value of acceleometer 

DigitalOut led1(LED1); //Device status LED

const static char     DEVICE_NAME[]        = "ACC1";    //Name of the Device in advertising mode
static const uint16_t uuid16_list[]        = {GattService::UUID_HEART_RATE_SERVICE,
                                              GattService::UUID_DEVICE_INFORMATION_SERVICE};
static volatile bool  triggerSensorPolling = false;

uint8_t hrmCounter = 0; // init HRM to 100bps

HeartRateService         *hrService;        //The Hear Rate Service instance
DeviceInformationService *deviceInfo;
 
/*
Name: checkMove function.
Description: It reads the accelerometer values and compares the current value to the Previous values. If there is a change in acceleration, it detects the movement and returns 1 for movement and 0 for no change.
*/ 
   
int checkMove(int x, int y, int z)
{
    int val = 0;
    acc.readXYZGravity(&x,&y,&z);
    Cx=x;
    Cy=y;
    Cz=z;
        
    if(Cx!=Px || Cy!=Py || Cz!=Pz)
    {  
    Px=Cx;
    Py=Cy;
    Pz=Cz;
    val=1;
    }
    else
    {val=0;
    }
    return val;
    
}

void disconnectionCallback(const Gap::DisconnectionCallbackParams_t *params)
{
    BLE::Instance(BLE::DEFAULT_INSTANCE).gap().startAdvertising(); // restart advertising
}

void periodicCallback(void)
{
    led1 = !led1; /* Do blinky on LED1 while we're waiting for BLE events */

    /* Note that the periodicCallback() executes in interrupt context, so it is safer to do
     * heavy-weight sensor polling from the main thread. */
    triggerSensorPolling = true;
}

void bleInitComplete(BLE::InitializationCompleteCallbackContext *params)
{
    BLE &ble          = params->ble;
    ble_error_t error = params->error;

    if (error != BLE_ERROR_NONE) {
        return;
    }

    ble.gap().onDisconnection(disconnectionCallback);

    /* Setup primary service. */
    hrService = new HeartRateService(ble, hrmCounter, HeartRateService::LOCATION_FINGER);

    /* Setup auxiliary service. */
    deviceInfo = new DeviceInformationService(ble, "ARM", "Model1", "SN1", "hw-rev1", "fw-rev1", "soft-rev1");

    /* Setup advertising. */
    ble.gap().accumulateAdvertisingPayload(GapAdvertisingData::BREDR_NOT_SUPPORTED | GapAdvertisingData::LE_GENERAL_DISCOVERABLE);
    ble.gap().accumulateAdvertisingPayload(GapAdvertisingData::COMPLETE_LIST_16BIT_SERVICE_IDS, (uint8_t *)uuid16_list, sizeof(uuid16_list));
    ble.gap().accumulateAdvertisingPayload(GapAdvertisingData::GENERIC_HEART_RATE_SENSOR);
    ble.gap().accumulateAdvertisingPayload(GapAdvertisingData::COMPLETE_LOCAL_NAME, (uint8_t *)DEVICE_NAME, sizeof(DEVICE_NAME));
    ble.gap().setAdvertisingType(GapAdvertisingParams::ADV_CONNECTABLE_UNDIRECTED);
    ble.gap().setAdvertisingInterval(1000); /* 1000ms */
    ble.gap().startAdvertising();
}


int main() {
  
    led1 = 1;
    Ticker ticker;
    ticker.attach(periodicCallback, 1); //Blink LED every second and transmit data evry second

    BLE& ble = BLE::Instance(BLE::DEFAULT_INSTANCE);
    ble.init(bleInitComplete);

    /* SpinWait for initialization to complete. This is necessary because the
     * BLE object is used in the main loop below. */
    while (ble.hasInitialized()  == false) { /* spin loop */ }
  
  while(1) {

    
    if (triggerSensorPolling && ble.getGapState().connected) {
        triggerSensorPolling = false;
        
        if(checkMove(x,y,z)!=0)   //Check the return value from checkMoe function and update the variable to transmit.
        hrmCounter=1;
        else
        hrmCounter=0;
        
    hrService->updateHeartRate(hrmCounter); ////Update the Movement value to the Service
    } else {
            ble.waitForEvent(); // low power wait for event
        }

      wait(.50);
   }
}

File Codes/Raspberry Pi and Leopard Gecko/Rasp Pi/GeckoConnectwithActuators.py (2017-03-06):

#!/usr/bin/env python
# Example of interaction with a BLE UART device using a UART service
# implementation.
# Author: Tony DiCola
#
# Code Modified for ECEN 5023 by Omkar Reddy Seelam and Rishabh Berlia
#
# Description: The Code flows like this
# 1.It Detects the Bluetooth adapter interfaced with the Rapsberry Pi ( In our Case IO Gear Bluetooth 4.0)
# 2.It Connects to the AdafruitBluefruit LE UART device on the Gecko
# 3.It Dicovers the UART service defined
# 4.It Starts Readind the data from the Device (It will read until one transmission has completed.)
# 5.We Parse the Values and store it in Appropriate variables.
# 6.We convert the status of the values into states (0 'OFF' and 1'ON')
# 7.We transmitted the converted Value to ThingSpeak
# 8.It actuates the actuators (Buzzer, Servo etc) if the conditions are met.
#
# Requirements to run this code:
# 1.Bluez 5.37 and above
# 2.Adafruit_Python Library for Bluefruit
# 3.Configure the bluetooth Deamon
# 4.Make sure the bluetooth is up and running by the code sudo hciconfig hci0 up
import time
import Adafruit_BluefruitLE
from Adafruit_BluefruitLE.services import UART

#############################################
import RPi.GPIO as GPIO
GPIO.setmode(GPIO.BOARD)

GPIO.setup(8,GPIO.OUT)                         # for RGB
#GPIO.setup(13,GPIO.OUT)                         # for RGB
#GPIO.setup(15,GPIO.OUT)                         # for RGB

#GPIO.output(13,0)                                       # for RGB
#GPIO.output(15,0)                                       # for RGB

pwm = GPIO.PWM(8,50)

GPIO.setup(7,GPIO.OUT)                          # for relay

GPIO.output(7,0)                                        # For the Relay (for the coffee machine)

def alarm():
    print "Intrusion Detected"
    GPIO.output(7,0)
    time.sleep(5)
    GPIO.output(7,1)

#def led():                                                                              # For turning on/off Bulbs
#    print 'LED'
#    GPIO.output(11,1)
#    time.sleep(0.01)
#    GPIO.output(13,1)
#    time.sleep(0.01)
#    GPIO.output(15,1)
#    time.sleep(0.01)
####################################################################


# Get the BLE provider for the current platform.
ble = Adafruit_BluefruitLE.get_provider()

#Convert Status Function
def ConvStatus(state):
    if state == 'Y':
	return 1
    else:
	return 0
# Main function implements the program logic so it can run in a background
# thread.  Most platforms require the main thread to handle GUI events and other
# asyncronous events like BLE actions.  All of the threading logic is taken care
# of automatically though and you just need to provide a main function that uses
# the BLE provider.
def main():
    while True:
        # Clear any cached data because both bluez and CoreBluetooth have issues with
        # caching data and it going stale.
        ble.clear_cached_data()
        # Get the first available BLE network adapter and make sure it's powered on.
        adapter = ble.get_default_adapter()
        adapter.power_on()
        print('Using adapter: {0}'.format(adapter.name))
        # Disconnect any currently connected UART devices.  Good for cleaning up and
        # starting from a fresh state.
        print('Disconnecting any connected UART devices...')
        UART.disconnect_devices()

        # Scan for UART devices.
        print('Searching for UART device...')
        try:
            adapter.start_scan()
            # Search for the first UART device found (will time out after 60 seconds but you 
            # can specify an optional timeout_sec parameter to change it).
            device = UART.find_device()
            if device is None:
                raise RuntimeError('Failed to find UART device!')
        finally:
            # Make sure scanning is stopped before exiting.
            adapter.stop_scan()

        print('Connecting to device...')
        device.connect()  # Will time out after 60 seconds, specify timeout_sec parameter
                          # to change the timeout.

        # Once connected do everything else in a try/finally to make sure the device
        # is disconnected when done.
        try:
            # Wait for service discovery to complete for the UART service.  Will
            # time out after 60 seconds (specify timeout_sec parameter to override).
            print('Discovering services...')
            UART.discover(device)

            # Once service discovery is complete create an instance of the service
            # and start interacting with it.
            uart = UART(device)

            # Write a string to the TX characteristic.
            # uart.write('RetTemp!')
            # print("Sent 'Command' to the device.")
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

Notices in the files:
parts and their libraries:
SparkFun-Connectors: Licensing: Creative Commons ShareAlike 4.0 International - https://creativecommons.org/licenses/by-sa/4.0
